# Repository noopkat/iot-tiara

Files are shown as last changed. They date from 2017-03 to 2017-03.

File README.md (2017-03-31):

# IoT Tiara

Get your nerdy twee on!

## What on Earth is this

I'm glad you asked! This repo holds all the files you need to create your very own IoT Tiara.

This tiara can light up in a variety of colours, controlled by the internet. You can control it any way you like, however the code setup in this repo will get you started with allowing your Twitch chat channel participants to do this by chat commands.

Here is a dorky photo of yours truly wearing it:

dork

## Is there a demo?

[There sure is!](https://youtu.be/mxmfkz-kXX0)

## How do I make one of my own?

You'll need:

+ [Adafruit Huzzah Breakout Board](https://www.adafruit.com/product/2471)
+ [FTDI Serial USB cable](https://www.adafruit.com/products/70)
+ Hookup wire
+ 3 RGB LEDs (common anode type)
+ 3 220 ohm resistors
+ [350mAh 3.7v LiPo battery](https://www.adafruit.com/products/2750)
+ [LiPo battery charger](https://www.adafruit.com/products/1304)
+ Super glue / nail glue
+ Hot glue gun
+ Electrical tape (~15mm wide)
+ Faux flowers (try Etsy)
+ Soldering iron + solder
+ Sidecutters
+ Wire stripper tool
+ Access to a 3D printer (or online, such as [Shapeways](http://shapeways.com))

1. Download and print each STL file on a 3D printer. Using [t-glase](http://taulman3d.com/t-glase-features.html) for the LED crystal shards looks really cool.
2. On the headband, use a hot soldering iron tip to melt 4 tiny holes for each RGB LED so the leads can be fed through the headband. Line up the printed crystal shards to mark the placement of these holes. [Reference photo](http://i.imgur.com/BpxyAZQ.jpg)
3. Feed the RGB LEDs through the headband, all in the same orientation. [Reference photo](http://i.imgur.com/oQRnDvE.jpg)
4. Connect the red LED leads together with wire and solder, on the underside of the headband. Do the same with the green, blue, and ground leads. [Reference photo](http://i.imgur.com/lxbLE2s.jpg)
5. Solder 2 connected headers to the VBatt and GND pinouts on the Huzzah. This is for the battery to plug into. Make sure the long ends of the header pins face upwards from the front of the board.
6. Solder 6 connected headers to the FTDI pinouts on the Huzzah. Make sure the long ends of the header pins face upwards from the front of the board.
7. Solder a resistor to each of the following pins: #12, #14, #16
8. Attach the case bottom to the bottom right side of the headband with electrical tape, via the slots in the bottom of the case. Place the Huzzah board into the 3D printed case bottom.
9. From the far right RGB LED, connect its leads to the board by tracing wire along the underside of the headband. Ground connects to the free GND pin, red to #16 resistor, green to #14 resistor, and blue to #12 resistor.
10. Time to test! Connect the FTDI friend to the Huzzah, the other end to your computer.
11. Edit src/tiara-MQTT.ino to include your own wifi and Azure IoT Hub credentials. See the next section below on how quick it is to get your IoT Hub and new device all set up first.
12. Compile and upload to the board. You're ready to test! See the software section below to get the rest up and running.
13. If the software and hardware is all working as expected, go ahead and glue the crystal shards to the headband with super glue / nail glue.
14. For extra twee-factor, hot glue some flowers to the band carefully. Hot glue can warp the printed headband, so go easy and use glue sparingly.
15. Attach the cover onto the Huzzah case bottom, and you're done!

## How do I set up the software for this?

1. Create an Azure account. It's free to join!
2. Create a new Azure IoT Hub instance following steps 1-6 of [these instructions](https://docs.microsoft.com/en-us/azure/iot-hub/iot-hub-node-node-getstarted). The free tier allows up to 8000 messages a day.
3. Create a new device within the Device Explorer after clicking on your IoT Hub instance from your Azure Dashboard. Remember the name you gave it, and generate a new SAS token for it to include in the Huzzah sketch (src/tiara-mqtt.ino)
4. You can run the server to listen to Twitch chat either locally, or you can host it in the cloud. You'll need NodeJS installed if you're going local. Whether local or cloud, you'll need to set the following environment variables:
  + `TWITCH_TOKEN` - go to Twitch, log in and [create a token to use](http://twitchapps.com/tmi/).
  + `TWITCH_NICK` - your Twitch username/nick
  + `TWITCH_CHANNEL` - which Twitch chat channel you want to listen to. Example: `#noopkat`
  + `IOT_CONN_STRING` - the connection string of your Azure IoT Hub instance. Find one under 'Shared Access Policies' after clicking on your Hub instance from the Dashboard.
  + `IOT_DEVICE_ID` - the name of the device you set up in the IoT Hub instance.
5. Deploy this repo to the cloud, or run it locally with `npm start`
6. Go to Twitch online, and type commands into the Twitch channel your server is listening on! Try `tiara red` (and other simple colour names) or even 6 digit hex colours! Like `tiara #00ff00` for instance. `tiara off` and `tiara on` also work.
7. Once you verify your tiara works, disconnect the FTDI cable and try plugging in your charged LiPo battery to go cable free!

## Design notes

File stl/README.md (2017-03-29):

# 3D files

## Attribution

The Huzzah breakout board case model file is a remix of: http://www.thingiverse.com/thing:2177951/. It was modified to include slots for pin access on the bottom of the case.

The remaining models are original creations by Suz Hinton.

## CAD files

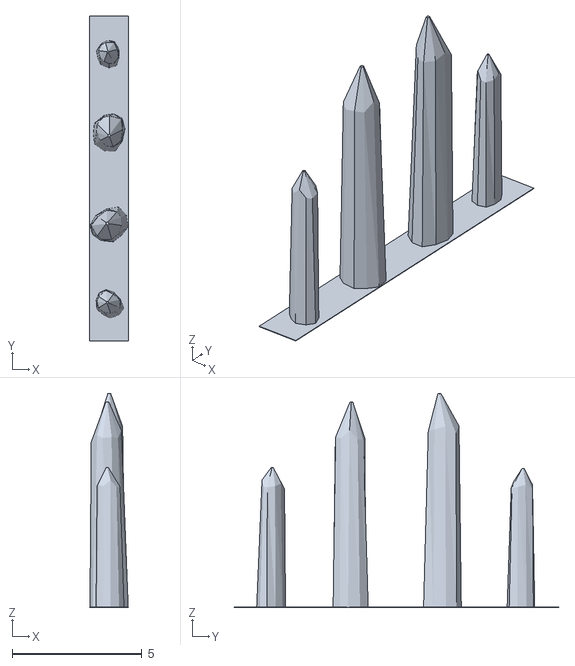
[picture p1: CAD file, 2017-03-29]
stl/shards-opaque-only.stl
1.50 x 12.5 x 8.24

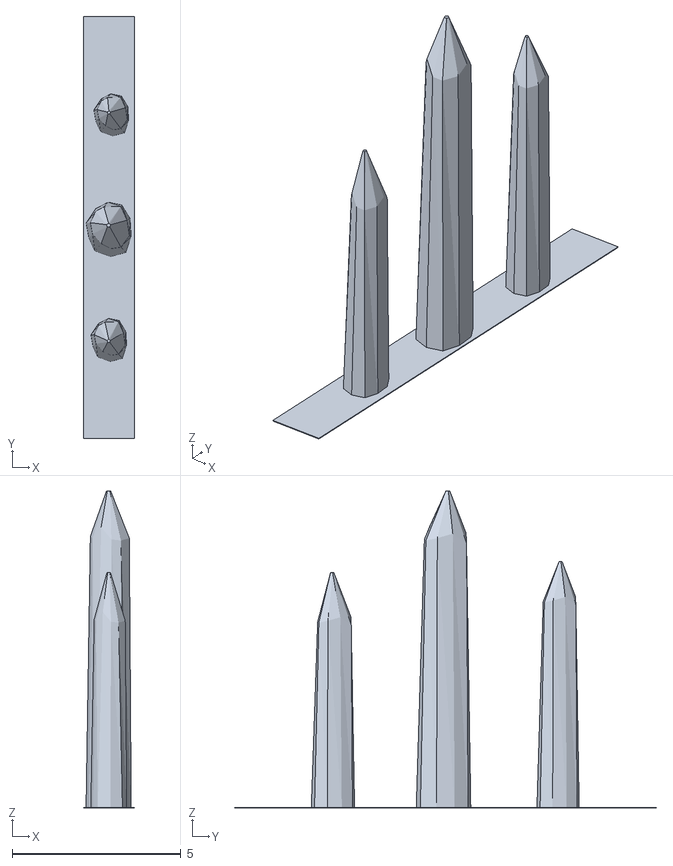
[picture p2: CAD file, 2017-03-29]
stl/shards-led-only.stl
1.50 x 12.5 x 9.39

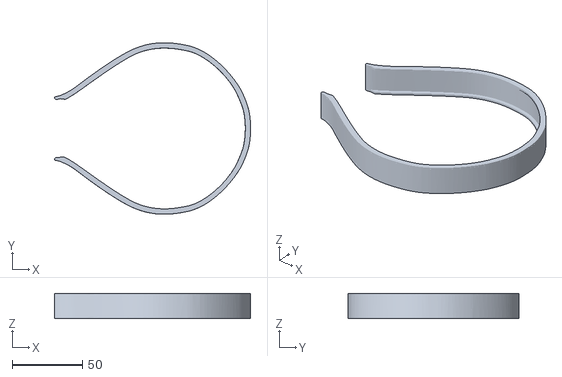
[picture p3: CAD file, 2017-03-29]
stl/headband.stl
139.6 x 122.1 x 17.8

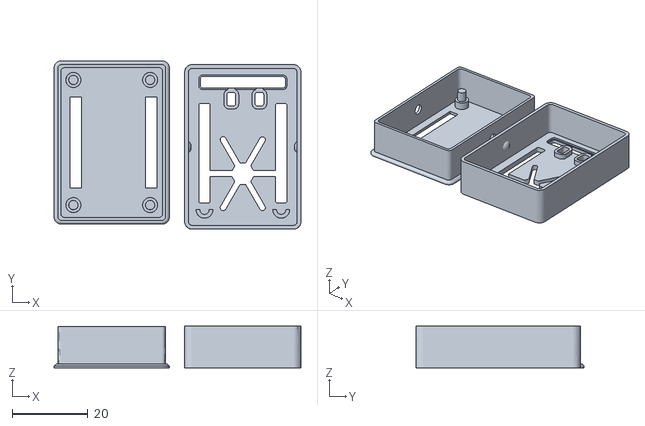
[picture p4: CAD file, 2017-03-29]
stl/huzzah-case.stl
65.4 x 44.6 x 11.1

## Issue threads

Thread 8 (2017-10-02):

Color picker usablity

svinkle, 2017-10-02:
I was just thinking about the usability and keyboard accessibility of #7. In order to avoid folks having to `Tab` through each individual item, which would be a pain, what if it was implemented as:

1. Add `tabindex="0"` to the container in order to add it to the focus order.
2. Add an `aria-label` to the container explaining what this thing is and how to use it.
3. Add `tabindex="-1"` to each item in order to be removed from focus order.
4. Implement arrow navigation via JS in order for a selection to be chosen.

`Enter` and `Space` support has already been implemented so you're good there.

Off the top of my head I'm not sure how you'd support up and down arrows, but left and right might be a matter of incrementing or decrementing some index value and setting focus to that item. Perhaps to collect each item it would need a `data-item-[index]` type attribute? Maybe up and down could just add or subtract some set value to the current index, like `10`? Just guessing here.

Keycodes:
- 👈 = 37
- 👆 = 38
- 👉 = 39
- 👇 = 40

Anyway, something to consider. Wanted to share this before I forgot. 🙂

orthros, 2017-11-08:
Hey thanks for bringing this up! Not sure how I missed the notification for it, but I'm glad I caught it!

I'll take a look at implementing your suggestions; I'm not a primary web ux dev, but I've been learning more about modern web dev of late so this'll be a fun challenge to tackle!

Thanks again 😸

orthros, 2017-11-08:
Hey thanks for bringing this up! Not sure how I missed the notification for it, but I'm glad I caught it!

I'll take a look at implementing your suggestions; I'm not a primary web ux dev, but I've been learning more about modern web dev of late so this'll be a fun challenge to tackle!

Thanks again 😸

orthros, 2017-11-08:
Hey thanks for bringing this up! Not sure how I missed the notification for it, but I'm glad I caught it!

I'll take a look at implementing your suggestions; I'm not a primary web ux dev, but I've been learning more about modern web dev of late so this'll be a fun challenge to tackle!

Thanks again 😸

svinkle, 2017-11-08:
@orthros Very cool! Let me know when you've got something an I'll give it a run though. 😀

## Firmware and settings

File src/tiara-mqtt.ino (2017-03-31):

#include <ESP8266WiFi.h>
#include <PubSubClient.h>
#include <WiFiClientSecure.h>

// wifi credentials
const char* ssid = "";
const char* password = "";

// mqtt / azure iot hub credentials

// example: <myiothub>.azure-devices.net
const char* mqtt_server = "";

// this is the id of the device created in Iot Hub
// example: myCoolDevice
const char* clientid = "";

// <myiothub>.azure-devices.net/<myCoolDevice>
const char* username = "";

// SAS token should look like "SharedAccessSignature sr=<myiothub>.azure-devices.net%2Fdevices%2F<myCoolDevice>&sig=123&se=456"
const char* token = "";

// default topic feed for subscribing is "devices/<myCoolDevice>/messages/devicebound/#""
const char* feed_endpoint = "";


WiFiClientSecure espClient;
PubSubClient client(espClient);

long lastMsg = 0;

// set pins for RGB LED
int redPin = 16;
int greenPin = 14;
int bluePin = 12;

// function to connect to the wifi
void setup_wifi() {
  delay(10);

  Serial.println();
  Serial.print("Connecting to wifi");

  WiFi.begin(ssid, password);

  while (WiFi.status() != WL_CONNECTED) {
    delay(500);
    Serial.print(".");
  }

  // debug wifi via serial
  Serial.println("");
  Serial.println("WiFi connected");
  Serial.println("IP address: ");
  Serial.println(WiFi.localIP());
}

// function to connect to MQTT server
void reconnect_mqtt() {
  // Loop until we're reconnected
  while (!client.connected()) {
    Serial.print("Attempting MQTT connection...");
    // Attempt to connect
    if (client.connect(clientid, username, token)) {
      Serial.println("connected"); 
      // ... and resubscribe
      client.subscribe(feed_endpoint);
    } else {
      Serial.print("failed, rc=");
      Serial.print(client.state());
      Serial.println(" try again in 5 seconds");
      // Wait 5 seconds before retrying
      delay(5000);
    }
  }
}


// callback function for when a message is dequeued from the MQTT server
void callback(char* topic, byte* payload, unsigned int length) {
  // print message to serial for debugging
  Serial.print("Message arrived: ");
  for (int i = 0; i < length; i++) {
    Serial.print((char)payload[i]);
  }
  Serial.println();

  if (length == 3) {
    int red = payload[0];
    int green = payload[1];
    int blue = payload[2];

    setColour(red, green, blue);
  }
}

// function to set RGB LED to custom colours
void setColour(int red, int green, int blue) {
  analogWrite(redPin, red);
  analogWrite(greenPin, green);
  analogWrite(bluePin, blue);
}

void setup() {
  // turn off onboard led
  pinMode(BUILTIN_LED, OUTPUT);
  digitalWrite(BUILTIN_LED, HIGH);

  // set up RGB led pins
  pinMode(redPin, OUTPUT);
  pinMode(greenPin, OUTPUT);
  pinMode(bluePin, OUTPUT);

  // begin serial for debugging purposes
  Serial.begin(115200);

  // connect to wifi
  setup_wifi();

  // set up connection and callback for MQTT server
  client.setServer(mqtt_server, 8883);
  client.setCallback(callback);

  // connect to MQTT
  reconnect_mqtt();
}


void loop() {
  client.loop();
  long now = millis();

  // debug mqtt connection every 10 seconds
  if (now - lastMsg > 10000) {
    lastMsg = now;

    Serial.print("is MQTT client is still connected: ");
    Serial.println(client.connected());
  }
}

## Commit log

2017-03-03 add IoT Hub sample
2017-03-05 create RGB LED control example
2017-03-29 add 3D files for printing
    [headband.stl, huzzah-case.stl, shards-led-only.stl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]
